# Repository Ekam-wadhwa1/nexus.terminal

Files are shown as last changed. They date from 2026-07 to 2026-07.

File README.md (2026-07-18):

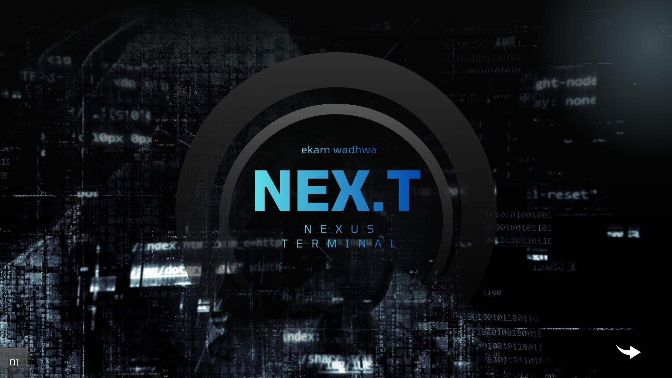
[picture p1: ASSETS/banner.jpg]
banner

# nexus terminal
this is a small handheld cyberdeck with a custom mechanical keyboard with macropad, rotary encoders and joystick for use as a reading terminal, hardware hacking tool or even a compact work station running windows, yes it can run full x86 windows

## Features

* **Custom Mechanical Keyboard:** Integrated layout featuring a dedicated macropad for custom shortcuts.
* **Tactile Controls:** Dual rotary encoders and a physical joystick for navigation and custom inputs.
* **keyboard display:** a 1.3" Oled display for setting macro's and show stats
* **Heavy Compute:** Powered by a LattePanda IOTA mainboard for full desktop-class performance in a portable form factor.
* **Fully Modular CAD:** Parametric case design optimized for 3D printing and easy hardware modification.
* **Active Cooling System:** Integrated cooling with a dedicated active cooler to maintain optimal temperatures under heavy processing loads.
* **Modular Type-C UART Interface:** An exposed Type-C module in keyboard wired for UART protocol, allowing you to instantly hot-plug custom external hardware modules, sensors, or debugging tools.

## Repository Structure

| Directory | Content Description |
| :--- | :--- |
| `ASSETS/` | Project imagery, graphics, and branding materials (e.g., banner, logos). |
| `CAD FILES/` | 3D mechanical assemblies separated into individual `STEP` and `STL` directories. |
| `DATASHEETS/` | Comprehensive hardware datasheets for core components (OLED, MCP23017, TP4056, switches, etc.). |
| `DIMENSIONS AND DRAWINGS/` | 2D layouts, dimensions, and reference drawings for the hardware displays. |
| `FUSION FILES/` | Original parametric design assets (`.f3d`) for custom individual components and sub-assemblies. |
| `KICAD FILES/KEYBOARD/` | Active development directory for the custom keyboard and macropad electronics engineering. |
| `PRINT FILES/` | Sorted, print-ready `.stl` slice files split by assembly groups (`DEVICE` vs `KEYBOARD`). |
| `PRODUCTION(KEYBOARD PCB)/` | Manufacturing-ready hardware deliverables (Gerber `.zip`, BOM, coordinate position files). |
| `scotto_kicad/` | Source hardware schematic captures, custom footprints, and layout design routing maps. |

 ## Getting Started

### Mechanical & CAD Files
* **For 3D Printing:** Navigate to `PRINT FILES/` or `CAD FILES/STL/`. The components are pre-oriented and split into clean assembly layers (`DEVICE` and `KEYBOARD`) for straightforward printing.
* **For Design History / Assembly:** Open the `.f3d` assets inside the `FUSION FILES/` directory using Autodesk Fusion to access the full parametric timeline and component design structure.

### Electronics & PCB Fabrication
* **Schematics & Layouts:** Open the `scotto_kicad/` directory using KiCad to view the schematic captures and matrix traces.
* **For Manufacturing:** Production-ready production outputs (including Gerber archives, component coordinates, and placement data) are fully generated and located in the `PRODUCTION(KEYBOARD PCB)/` folder.

### Modular Hacking Interface
* The integrated Type-C interface breaks out **UART** communication protocol pins. Custom external peripheral modules can be hot-plugged directly into this bus for hardware expansion.

## credits
keyboard footprint and kicad library- [joe scotto][scotto] <br>
documentation for lattepanda iota- [lattepanda][panda] <br>
documentation for 7 inch display- [display 7"][panda2] <br>
documentation for 7.9 inch display- [display7.9"][waveshare] <br>

## License
This project is licensed under the terms found in the [LICENSE](LICENSE) file included in this repository.

## badges
 <br>
 <br>
 <br>
 <br>

## about me
im just a student trying my best to do stuff i like

connect here


### links
[scotto]: https://github.com/joe-scotto/scottokeebs
[panda]: https://docs.lattepanda.com/content/iota_edition/specification/
[panda2]: https://docs.lattepanda.com/content/iota_edition/product_catalog/
[waveshare]: https://www.waveshare.com/wiki/7.9inch_HDMI_LCD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

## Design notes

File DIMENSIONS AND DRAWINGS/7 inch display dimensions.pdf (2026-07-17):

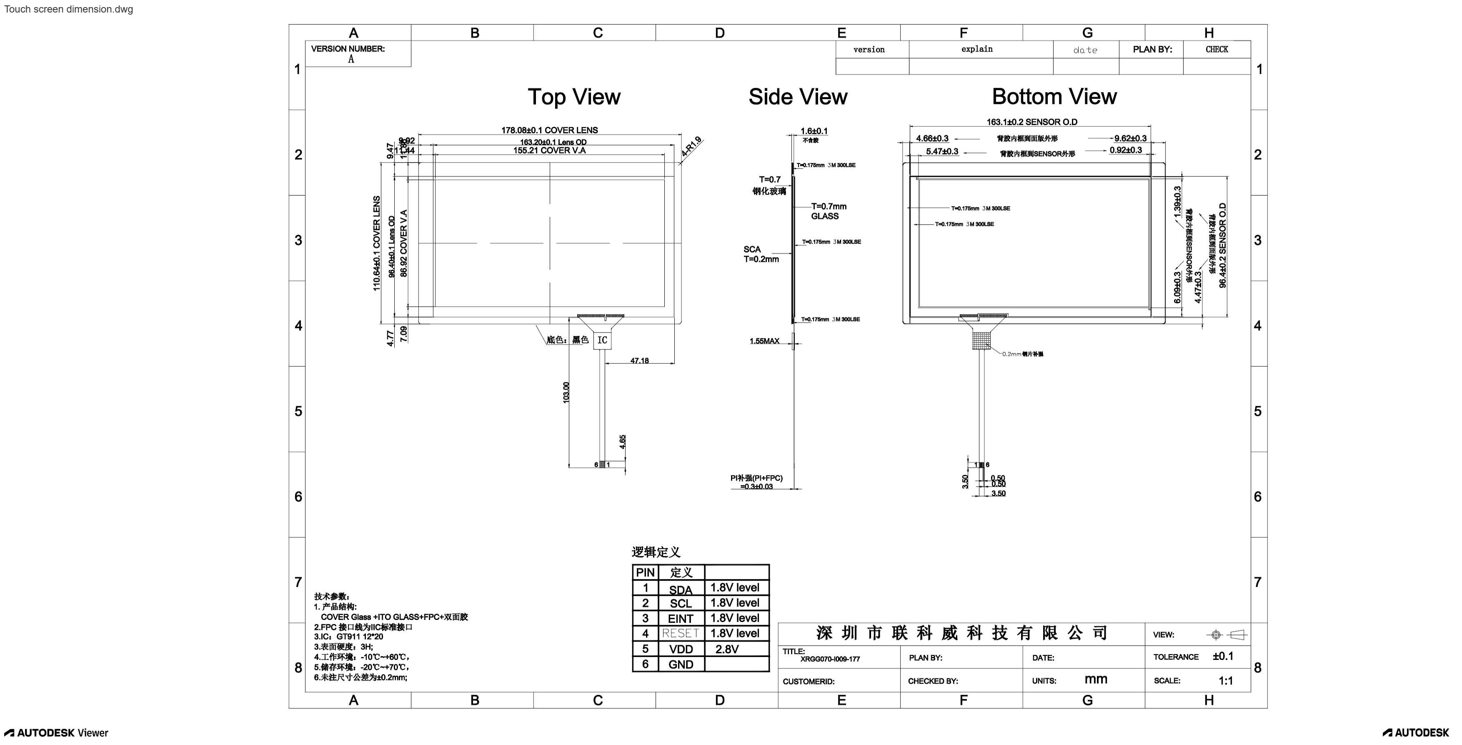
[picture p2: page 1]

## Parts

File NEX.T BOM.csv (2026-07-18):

Component Name | Category | Quantity | Description | Purchase Link | price in INR | price in USD
Kailh Box Cream Pro Switch | Keyboard - Switches | 9 | Linear mechanical switches for the keyboard deck matrix | Kailh Box Cream Pro Switch : Meckeys.com | 3420 | 35.5193676
YKYIO Keycap Set | Keyboard - Keycaps | 1 | Keycap set for custom integrated mechanical deck layout | Ykyio Keycap Set : Meckeys.com | 1599 | 16.60686222
4Pin OLED Display Module (Blue) | Keyboard - Display | 1 | Auxiliary 1.3 inch SH1106 OLED screen for status readouts and macros | 0.96 Inch I2C/IIC 4pin OLED Display Module Blue color | Robu.in | 179 | 1.85905462
MCP23017-E/SP IC | Keyboard - IC Expander | 1 | 16-Bit I2C I/O Expander in a DIP-28 package for routing keyswitch matrix | MCP23017-E/SP-MICROCHIP-I/O Expander, 16 bit, I2C, Serial, 1.8 V, 5.5 V, DIP, 28 Pins | Robu.in | 259 | 2.68991702
Adafruit Analog Joystick | Keyboard - Navigation | 1 | Thumb joystick providing physical XY directional inputs | 2765 Adafruit Industries LLC | Navigation Switches, Joystick | DigiKey | 236 | 2.45104408
XH-A 2.5mm 2-Pin Wafer Male | Keyboard - Connector | 1 | Through-hole straight male header for internal wiring harnesses | XH-A-2.5mm-2 pin Wafer Male Connector Through Hole Straight | Robu.in | 0.58 | 0.0060237524
TP4056 Charger Board | Keyboard - Power Management | 1 | Lithium battery charging control module with overcurrent protection | TP4056 SMD IC | Robu.in | 14 | 0.14540092
KP-357090 3.7v Rechargeable Battery | keyboard - power | 1 | 4000mah slim battery for powering the keyboard | KP-357090 3.7v 4000mAh 2wire Rechargeable Battery for DVD, Tablet, MP3 Player, 4000 mah : Amazon.in | 585 | 6.0756813
Resistor Box Assortment | Keyboard - Passives | 1 | Assorted passive resistors for pull-ups, current limiting, and filtering | Buy Resistor box Online in India | Robocraze | 45 | 0.4673601
1N914TR ONSEMI Diodes | Keyboard - Diodes | 90 | General purpose DO-35 switching diodes to handle ghosting in matrix rows | 1N914TR-Onsemi-200mA 1V@10mA 100V DO-35 Diodes - General Purpose ROHS | 435.6 | 4.524045768
Espressif ESP32-C6-DevKitC-1-N8 | Keyboard - MCU | 1 | Core RISC-V development board managing input control, wireless, and coordination | Buy Espressif ESP32-C6-DevKitC-1-N8 Development Board online | Robu.in | 1149 | 11.93326122
EC12 Rotary Encoder (15mm) | Keyboard - Control | 2 | Tactile incremental encoders for custom parameter tuning and volume control | EC12 Rotary Encoder 15mm Handle Audio Digital Potentiometer – REES52 | 98 | 1.01780644
Type-C 6Pin SMD Female Connector | Keyboard - Port | 1 | Minimal Type-C port used explicitly for power input rails into the TP4056 charger | U262-061N-4BVC11-XKB-5A 1 6P Female -25℃~+85℃ Type-C SMD USB Connectors ROHS | 5 | 0.0519289
Type-C 16Pin Receptacle Breakout | Keyboard - Port | 1 | Standard Type-C interface breaking out UART connection protocol pins for expansion | Buy Now U262-161N-4BVC11 at Best Price | Robu.in | 27 | 0.28041606
Pro Range 3mm LED Kit (100pcs) | Keyboard - Indicators | 1 | 5-color F3mm structural indicator LEDs for status feedback | Buy Pro-Range 100PCS 5 Colors F3mm LED Kit Online at Robu.in | 122 | 1.26706516
Asceny Double-Sleeved USB-C Cable | Keyboard - Cable | 1 | Coiled mechanical keyboard cable for connection interfaces | ASCENY Coiled & Double-Sleeved Mechanical Keyboard Cable, for Type-C Mechanical Keyboards (Blue) : Amazon.in | 992 | 10.30269376
custom PCB | keyboard- pcb | 1 | the custom pcb for everythihng |  | 10669 | 110.8058868
LattePanda IOTA Mainboard | Main Device - Compute | 1 | Palm-sized x86 Single Board Computer running primary terminal OS environment | Buy LattePanda IOTA x86 SBC Intel N150 16GB RAM | Robu.in | 31419 | 326.3108218
LattePanda IOTA Active Cooler | Main Device - Cooling | 1 | Integrated aluminum heatsink and active cooling fan system for temperature control | LattePanda IOTA Active Cooler (Aluminum Heatsink & Fan) | 1199 | 12.45255022
Waveshare 7.9" 400x1280 IPS Screen | Main Device - Display | 1 | Ultra-wide bar format capacitive touch display with hardened glass cover | Buy Waveshare 7.9inch 400×1280 HDMI IPS Capacitive Touch Screen LCD With Toughened Glass Cover | Robu.in | 6861 | 71.25683658
LattePanda 7" eDP Touch Display | Main Device - Display Opt. | 1 | Alternative 7-inch embedded DisplayPort native IPS touch screen panel asset | Buy 7" eDP IPS Touch Display for LattePanda IOTA | Robu.in | 8699 | 90.34590022
Waveshare DIY HDMI FFC Cable (0.5m) | Main Device - Interconnect | 1 | Flexible Flat Cable (FFC) ribbon path for tight internal chassis display routing | Waveshare DIY HDMI Cable: 0.5m FFC | Robu.in | 75 | 0.7789335
Waveshare DIY HDMI Straight Adapter | Main Device - Interconnect | 2 | Rigid straight HDMI connector plug adapter mating with the ribbon cable system | Buy Waveshare Straight Standard HDMI-Male to FFC 20PIN 0.5Pitch Female Adapter for DIY HDMI Cable online | Robu.in | 324 | 3.36499272
 |  |  |  |  | 68412.18 | 710.5138508

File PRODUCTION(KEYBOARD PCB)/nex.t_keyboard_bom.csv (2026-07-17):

Designator | Footprint | Quantity | Value | LCSC Part #
BT1 | JST_PH_B2B-PH-K_1x02_P2.00mm_Vertical | 1 | Battery_Cell
D1, D10, D11, D12, D13, D14, D15, D17, D18, D19, D2, D20, D21, D22, D23, D24, D25, D26, D27, D28, D29, D3, D30, D33, D34, D35, D36, D37, D38, D39, D4, D40, D41, D42, D43, D44, D45, D46, D49, D5, D50, D51, D52, D53, D54, D55, D56, D57, D58, D59, D6, D60, D61, D65, D66, D67, D68, D69, D7, D70, D71, D72, D73, D74, D75, D76, D77, D8, D81, D82, D83, D86, D9, D90, D91, D92, D93, D94 | Diode_DO-35 | 78 | ~
D16, D31 | LED_D3.0mm_Horizontal_O1.27mm_Z10.0mm | 2 | LED
J1 | OLED_128x64 | 1 | OLED_128x64
J2 | USB_C_Receptacle_GCT_USB4105-xx-A_16P_TopMnt_Horizontal | 1 | USB_C_Receptacle_USB2.0_14P
J3 | USB_C_Receptacle_GCT_USB4125-xx-x_6P_TopMnt_Horizontal | 1 | USB_C_Receptacle_PowerOnly_6P
R1, R2 | R_Axial_DIN0204_L3.6mm_D1.6mm_P5.08mm_Horizontal | 2 | Resistor
R3, R4 | R_Axial_DIN0204_L3.6mm_D1.6mm_P5.08mm_Horizontal | 2 | R
S1, S10, S11, S12, S13, S14, S15, S17, S18, S19, S2, S20, S21, S22, S23, S24, S25, S26, S27, S28, S29, S3, S34, S35, S36, S37, S38, S39, S4, S40, S41, S42, S43, S44, S45, S5, S50, S51, S52, S53, S54, S55, S56, S57, S58, S59, S6, S60, S66, S67, S68, S69, S7, S70, S71, S72, S73, S74, S75, S77, S8, S9, S90, S91, S92, S93, S94 | MX_PCB_1.00u | 67 | ~
S16 | Joystick_2765 | 1 | Joystick_2765
S30 | MX_PCB_2.00u | 1 | ~
S33, S46 | MX_PCB_1.50u | 2 | ~
S49, S76 | MX_PCB_1.75u | 2 | ~
S61, S65 | MX_PCB_2.25u | 2 | ~
S81, S82, S83 | MX_PCB_1.25u | 3 | ~
S86 | MX_PCB_6.25u | 1 | ~
SW1, SW2 | RotaryEncoder_Alps_EC12E-Switch_Vertical_H20mm_CircularMountingHoles | 2 | RotaryEncoder_Switch
U1 | ESP32-C6-DevKitC-1 | 1 | ESP32-C6-DevKitC-1
U2 | DIP-28_W7.62mm | 1 | MCP23017_SP
U3 | SOIC-8-1EP_3.9x4.9mm_P1.27mm_EP2.41x3.3mm_ThermalVias | 1 | TP4056-42-ESOP8

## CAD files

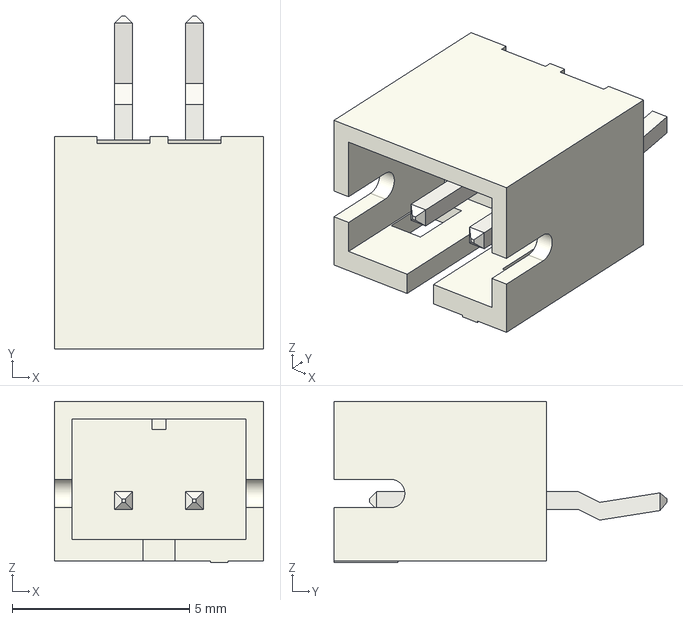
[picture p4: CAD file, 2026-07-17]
CAD FILES/STEP/COMPONENTS/JST CONNECTOR.step
5.90 x 9.40 x 4.55 mm

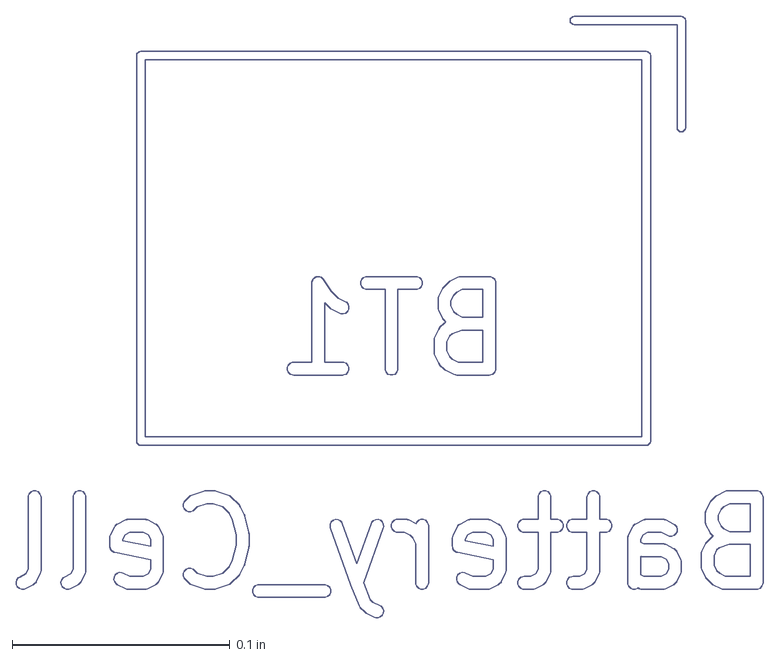
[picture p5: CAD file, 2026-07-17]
KICAD FILES/KEYBOARD/keyboard and macropad-B_Fab.dxf
0.343 x 0.276 in

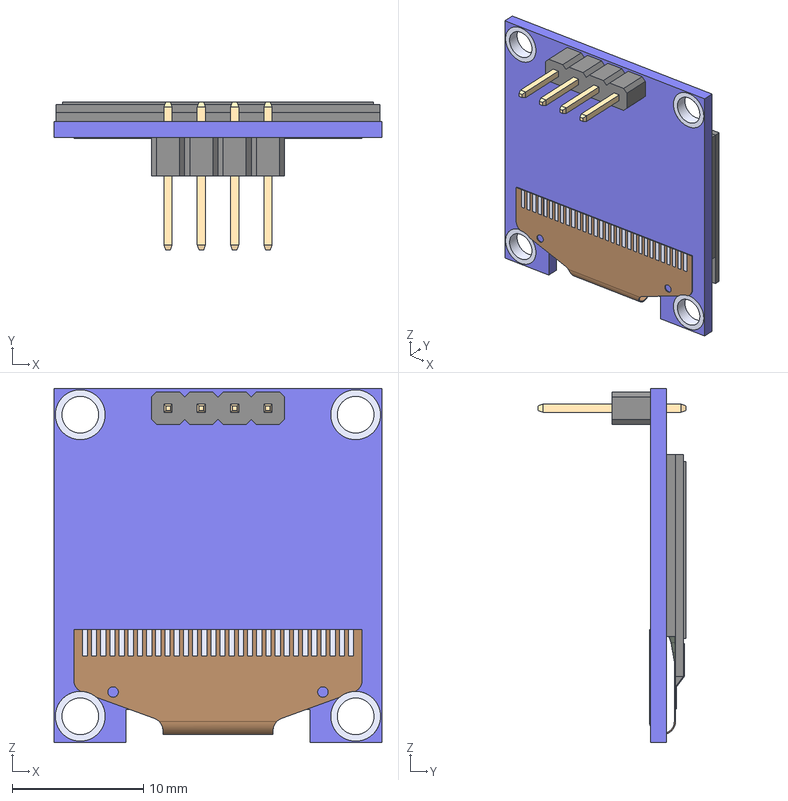
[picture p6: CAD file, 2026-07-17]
CAD FILES/STEP/COMPONENTS/OLED.step
25.0 x 11.3 x 27.0 mm

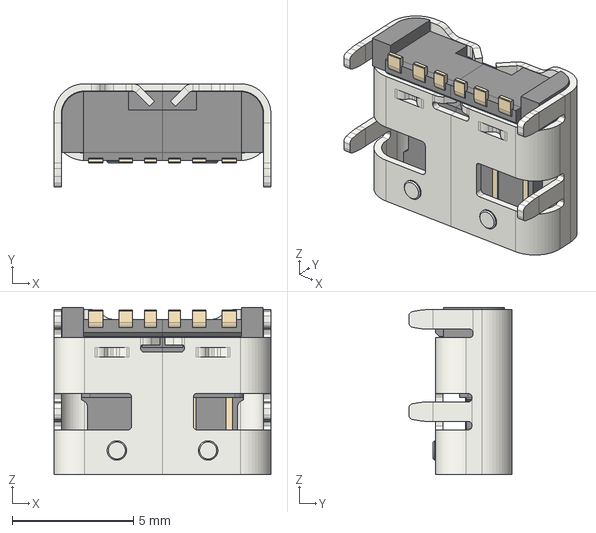
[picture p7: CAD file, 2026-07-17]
CAD FILES/STEP/COMPONENTS/USB C RECEPTACLE 6 PIN.step
8.94 x 4.26 x 6.90 mm

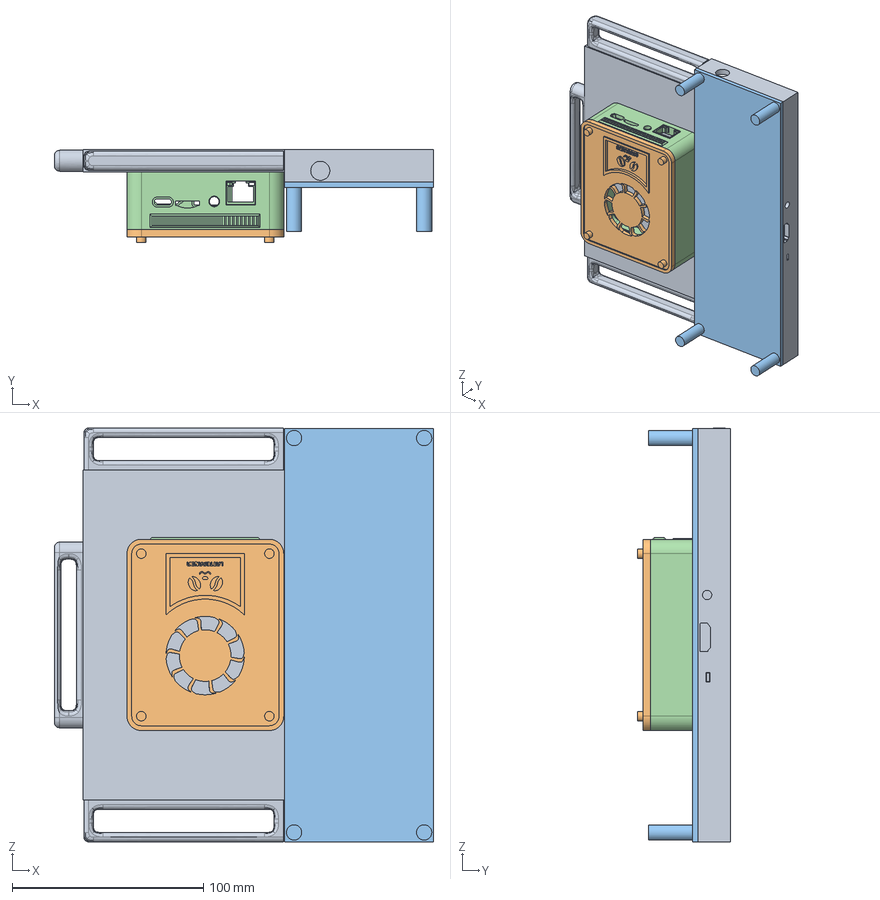
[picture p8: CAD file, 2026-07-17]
CAD FILES/STEP/DEVICE 3D PRINTABLE CASE.step
198.4 x 48.8 x 216.5 mm

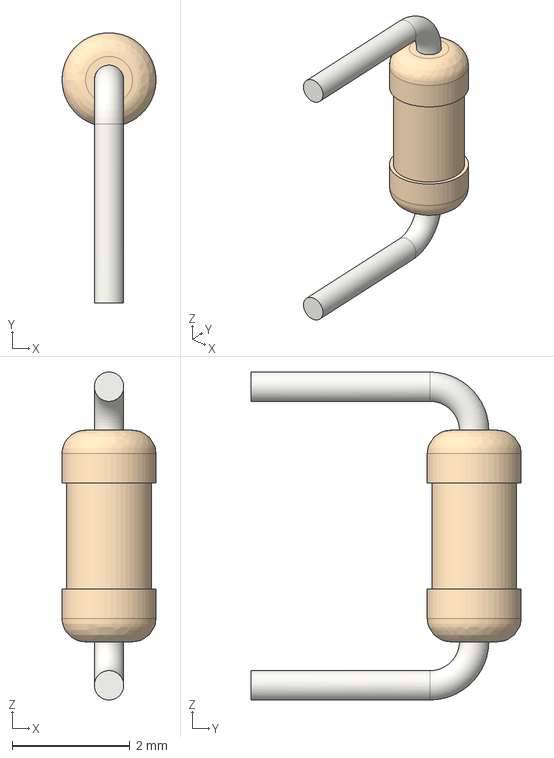
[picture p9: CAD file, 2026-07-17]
CAD FILES/STEP/COMPONENTS/RESISTOR.step
1.60 x 4.60 x 5.58 mm

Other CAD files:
CAD FILES/STEP/LattePanda IOTA Mainboard.stp
CAD FILES/STEP/FIT1027 Active Cooler.stp
CAD FILES/STL/COMPONENTS/OLED_128x64.stl
CAD FILES/STL/KEYBOARD PCB WITH COMPONENTS.stl
DIMENSIONS AND DRAWINGS/7.9inch HDMI LCD 3D Drawing/0820-1.stp
PRINT FILES/DEVICE/LATTEPANDA LID.stl
PRINT FILES/KEYBOARD/keyboard bottom.stl
CAD FILES/STL/KEYBOARD WITH COMPONENTS.stl
PRINT FILES/DEVICE/DISPLAY CASE.stl
PRINT FILES/KEYBOARD/keyboard top.stl
PRINT FILES/DEVICE/DISPLAY LID.stl
PRINT FILES/KEYBOARD/keyboard middle.stl
CAD FILES/STEP/COMPONENTS/Diode DO-35.step
CAD FILES/STEP/COMPONENTS/MCP23017.step
CAD FILES/STEP/COMPONENTS/MX KEYSWITCH.step
CAD FILES/STEP/COMPONENTS/USB C RECEPTACLE 14 PIN.step
CAD FILES/STL/COMPONENTS/Diode_DO-35.stl
CAD FILES/STL/COMPONENTS/JST CONNECTOR.stl
CAD FILES/STL/COMPONENTS/MCP23017.stl
CAD FILES/STL/COMPONENTS/RESISTOR.stl
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

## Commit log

2026-05-09 Enhance README with device specifications
    Added detailed specifications of the device's keyboard and battery management system.
2026-05-09 Change design badge from EasyEDA to KICAD
    Updated design badge from EasyEDA to KICAD.
2026-05-09 Change design badge from EasyEDA to KICAD
    Updated badge for design tool from EasyEDA to KICAD.
2026-05-16 Add initial diagram configuration for ESP32 project
2026-07-17 project upload
    [0820-1.stp, DEVICE 3D PRINTABLE CASE.step, DEVICE 3D PRINTABLE CASE.stl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]
2026-07-18 large files upload
    [0820-1.stp, DEVICE 3D PRINTABLE CASE.stl, DEVICE CASE.f3z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]
2026-07-18 ADD BOM
    [NEX.T BOM.csv]
